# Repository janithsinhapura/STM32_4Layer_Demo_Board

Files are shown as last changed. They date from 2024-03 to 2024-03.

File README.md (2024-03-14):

Contains the project files of the design of a 4 layer STM32F103c8t6 Demo Board

+ SPI
+ I2C
+ UART
+ USB
  
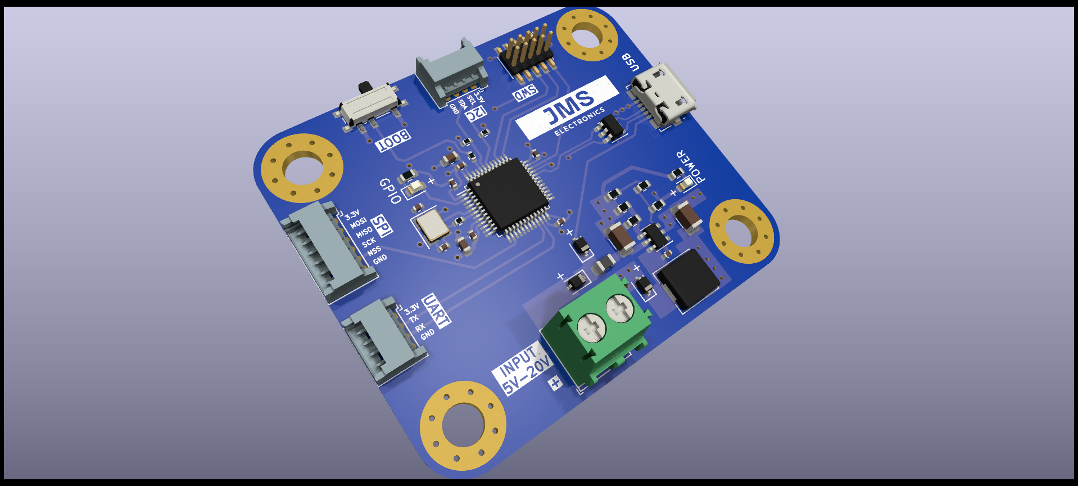
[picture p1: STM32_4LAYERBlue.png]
#D View

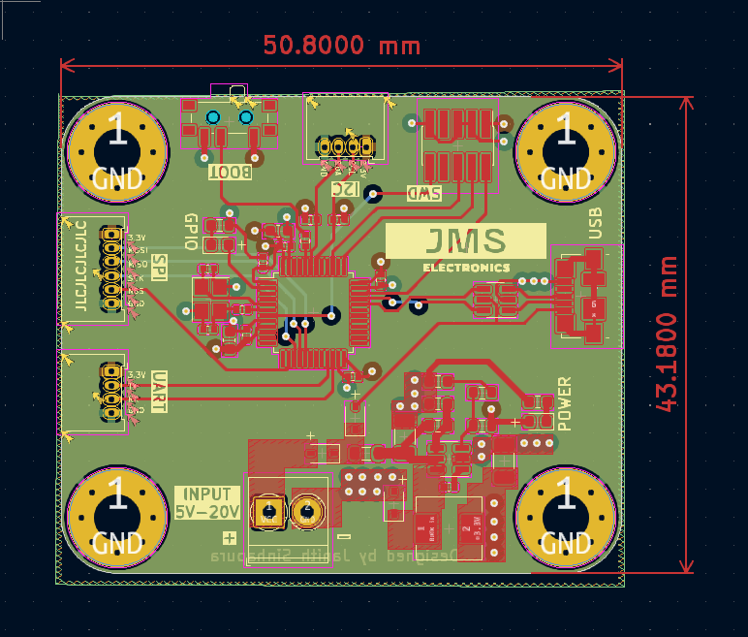
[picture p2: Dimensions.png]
Dimensions


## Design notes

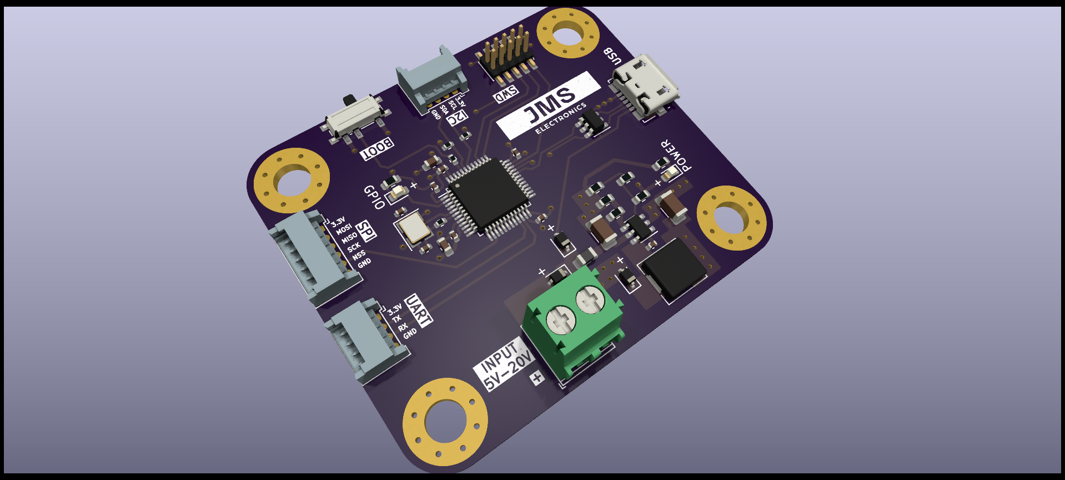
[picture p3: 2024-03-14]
STM32_4LAYER2RAY.png

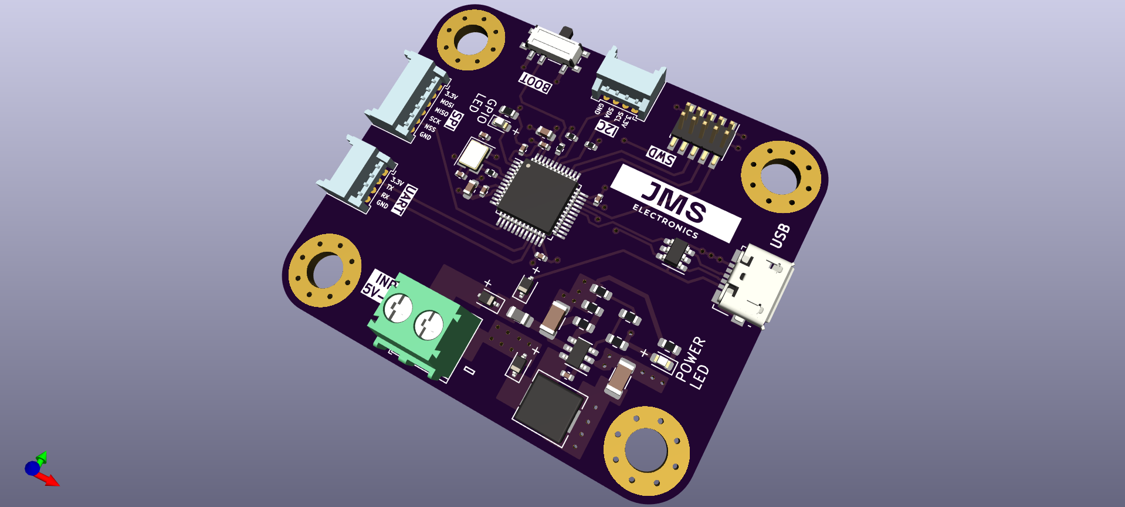
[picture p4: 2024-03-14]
STM32_4LAYER.png

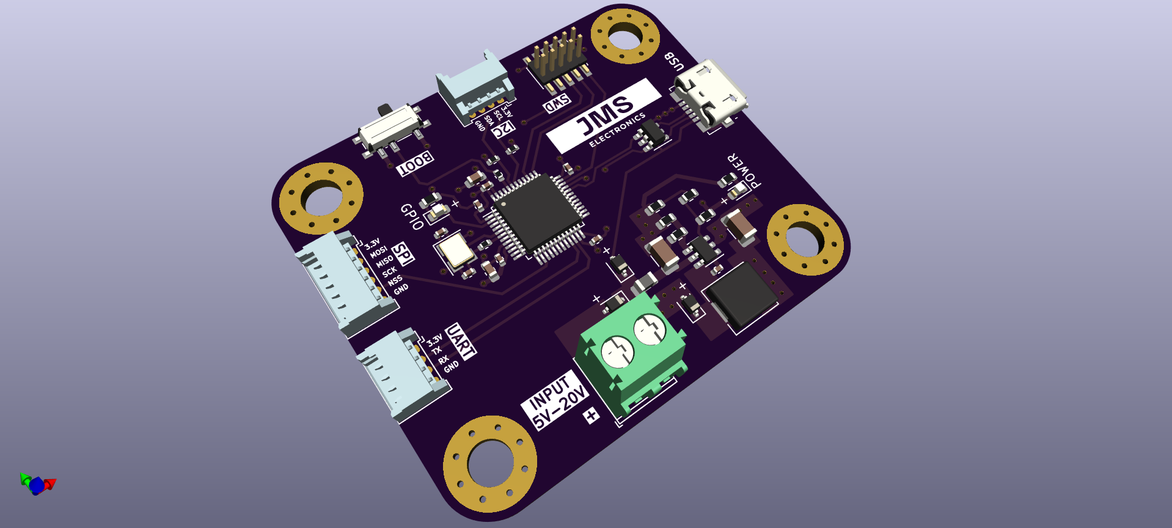
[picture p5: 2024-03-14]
STM32_4LAYER2.png

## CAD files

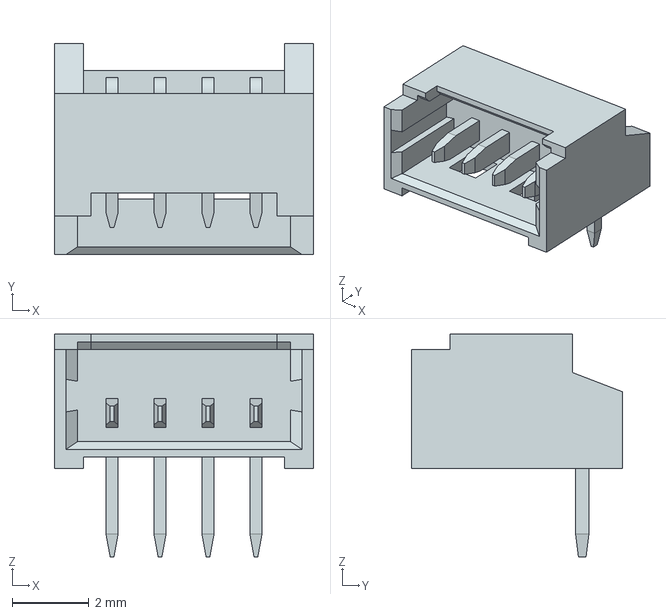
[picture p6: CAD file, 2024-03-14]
3d Models/I2C.stp
6.75 x 5.50 x 5.80 mm

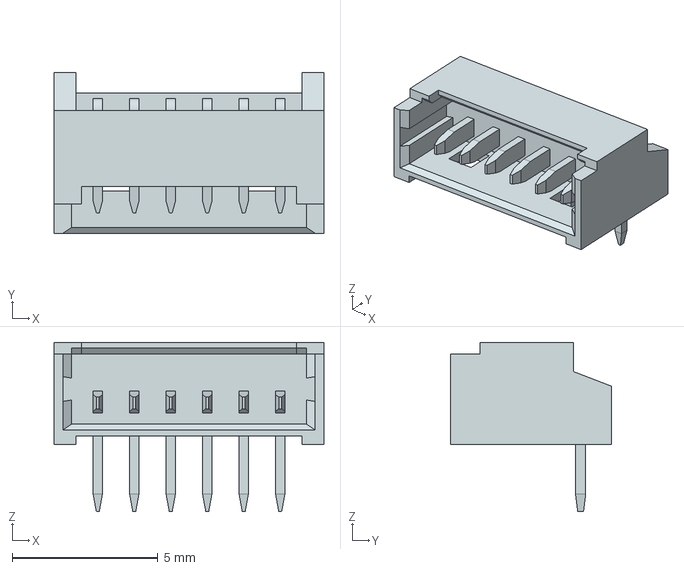
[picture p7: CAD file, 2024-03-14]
3d Models/UART.stp
9.25 x 5.50 x 5.80 mm

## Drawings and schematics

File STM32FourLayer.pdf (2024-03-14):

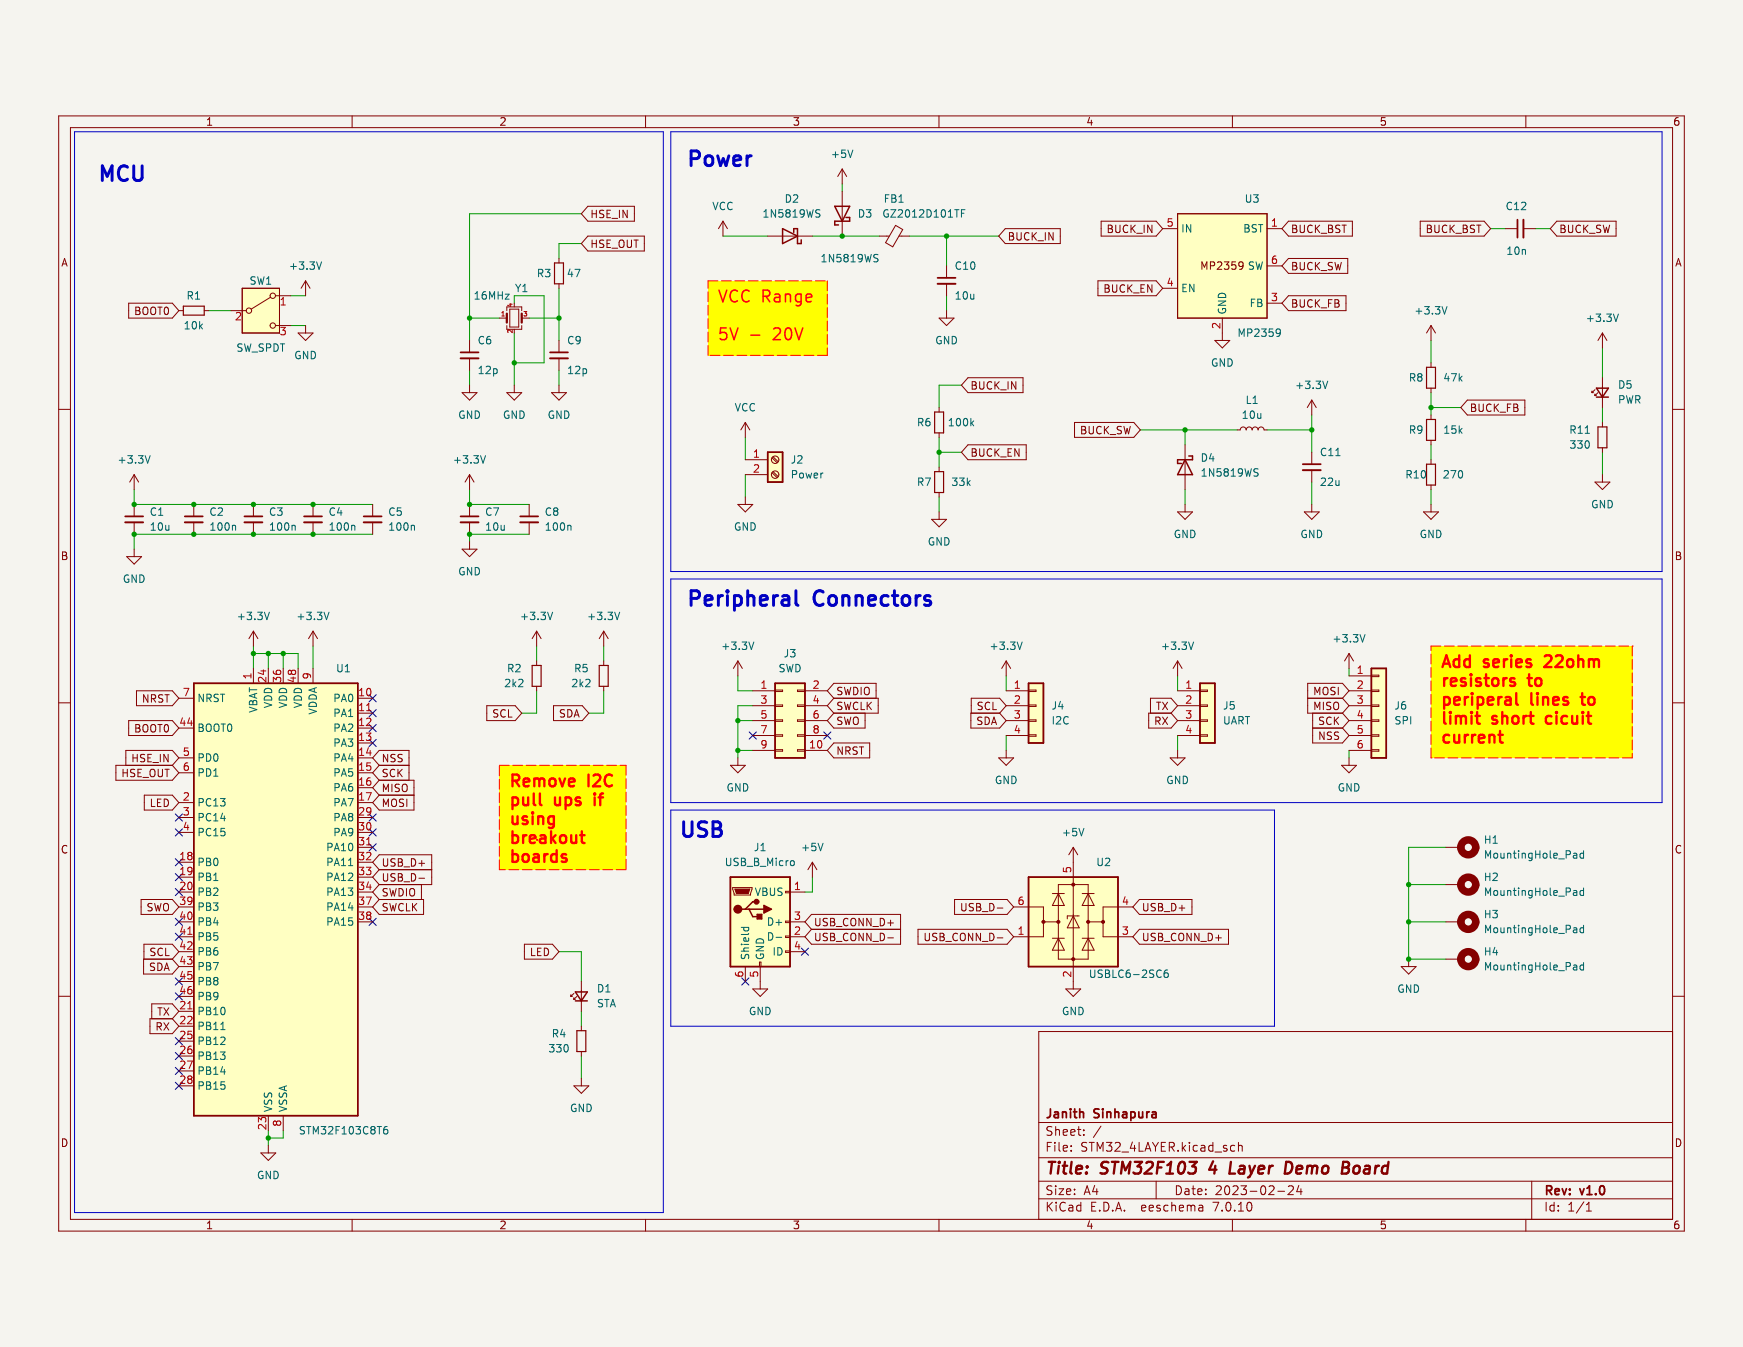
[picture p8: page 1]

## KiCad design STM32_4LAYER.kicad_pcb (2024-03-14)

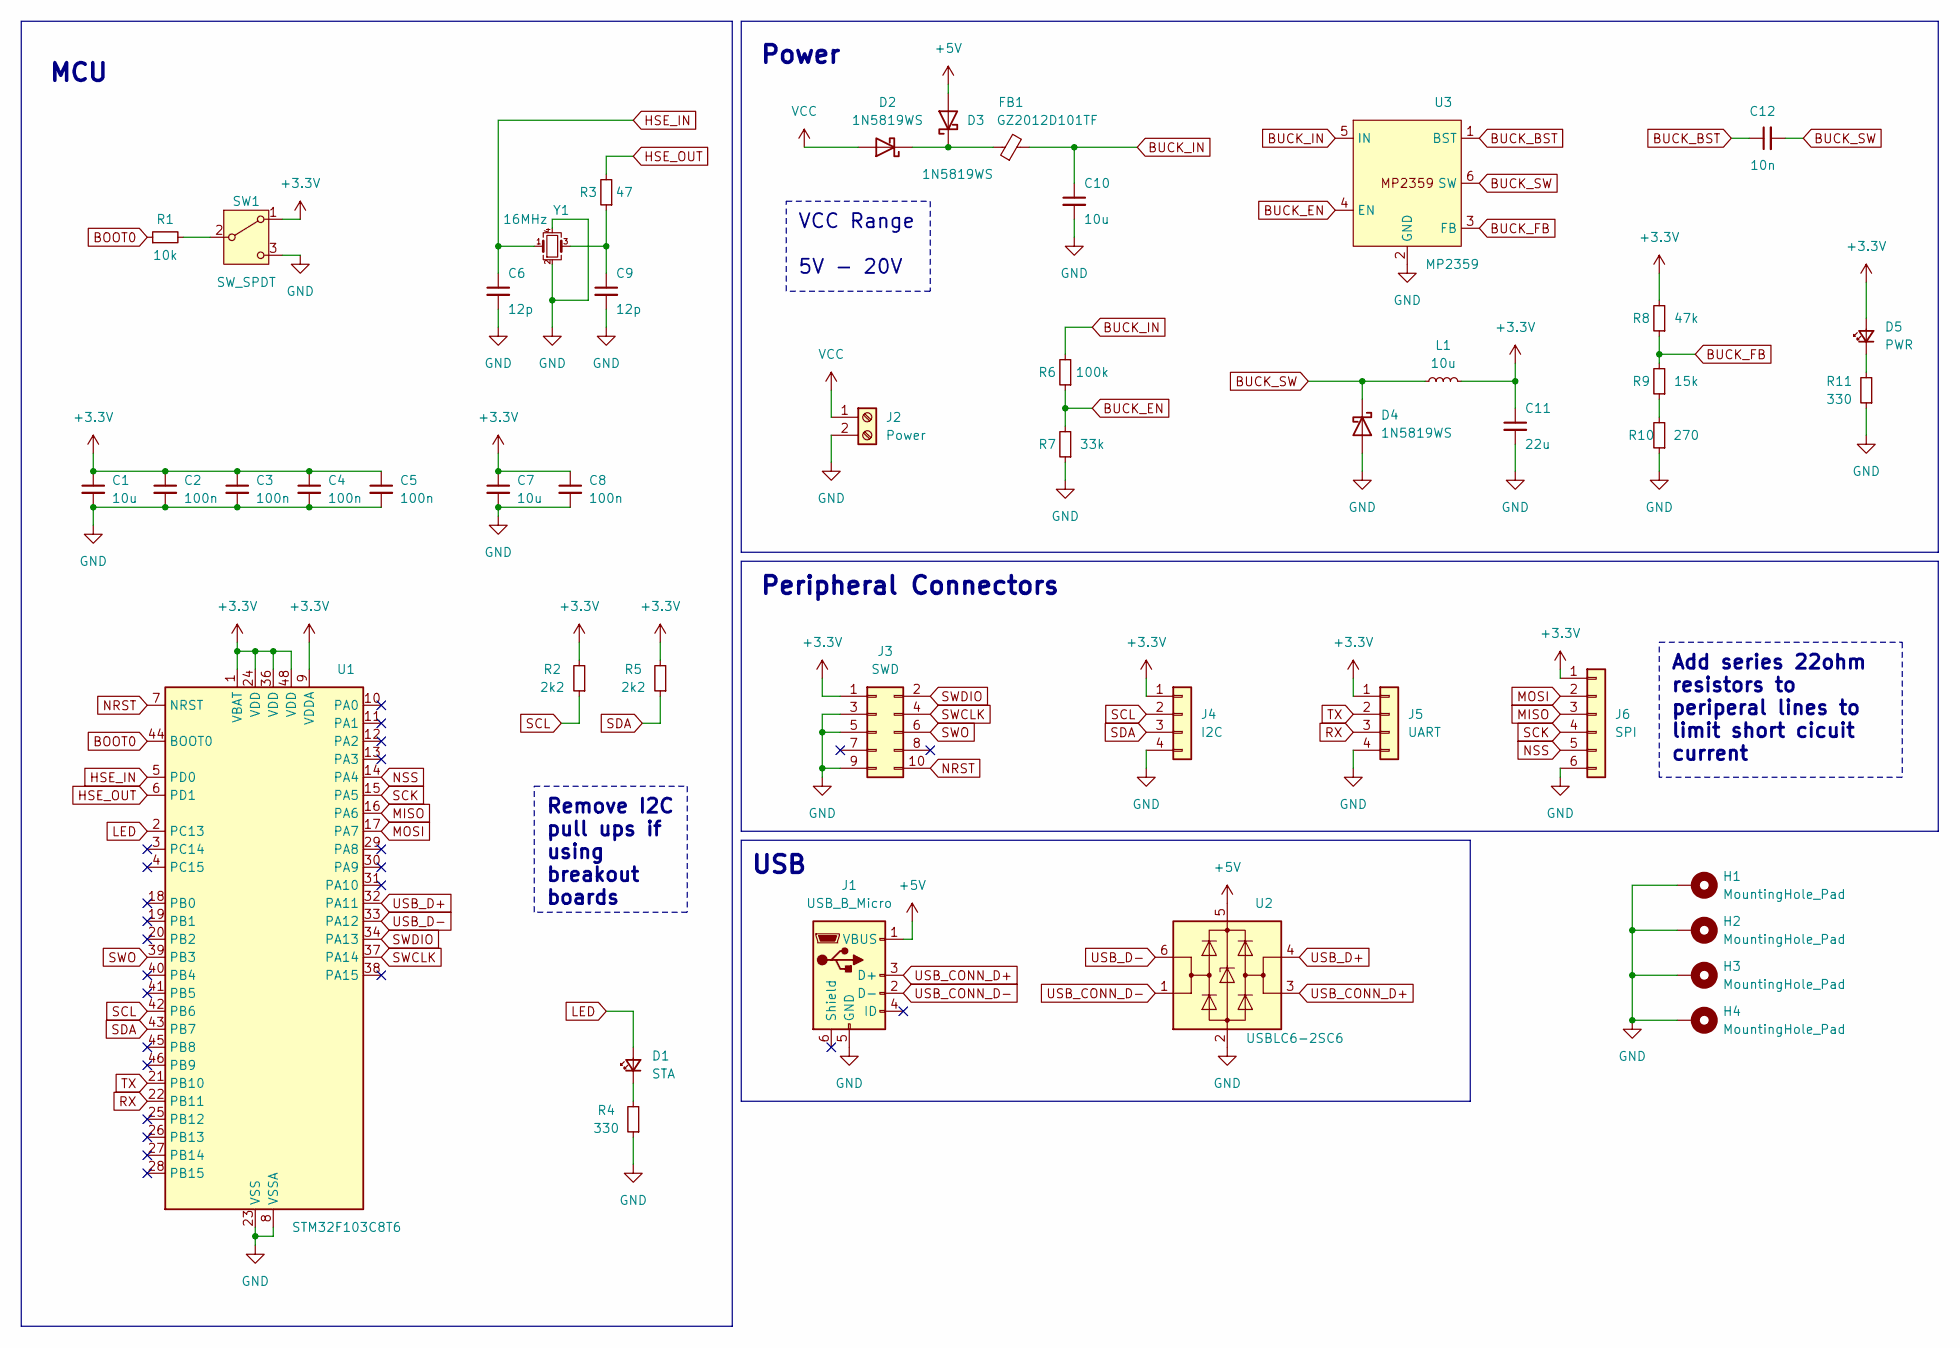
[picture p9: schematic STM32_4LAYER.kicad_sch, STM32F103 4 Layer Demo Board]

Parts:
C1, C7: 10u; C_0603_1608Metric
C2, C3, C4, C5, C8: 100n; C_0402_1005Metric
C6, C9: 12p; C_0402_1005Metric
C10: 10u; C_1206_3216Metric
C11: 22u; C_1206_3216Metric
C12: 10n; C_0402_1005Metric
D1: STA; LED_0603_1608Metric
D2, D3, D4: 1N5819WS; D_SOD-323
D5: PWR; LED_0603_1608Metric
FB1: GZ2012D101TF; L_0805_2012Metric
H1, H2, H3, H4: MountingHole_Pad; MountingHole_4.3mm_M4_Pad_Via
J1: USB_B_Micro; USB_Micro-B_Molex_47346-0001
J2: Power; TerminalBlock_Phoenix_PT-1,5-2-3.5-H_1x02_P3.50mm_Horizontal
J3: SWD; PinHeader_2x05_P1.27mm_Vertical_SMD
J4: I2C; Molex_PicoBlade_53048-0410_1x04_P1.25mm_Horizontal
J5: UART; Molex_PicoBlade_53048-0410_1x04_P1.25mm_Horizontal
J6: SPI; Molex_PicoBlade_53048-0610_1x06_P1.25mm_Horizontal
L1: 10u; L_Sunlord_MWSA0518S
R1: 10k; R_0402_1005Metric
R2, R5: 2k2; R_0402_1005Metric
R3: 47; R_0402_1005Metric
R4, R11: 330; R_0603_1608Metric
R6: 100k; R_0603_1608Metric
R7: 33k; R_0603_1608Metric
R8: 47k; R_0603_1608Metric
R9: 15k; R_0603_1608Metric
R10: 270; R_0603_1608Metric
SW1: SW_SPDT; SW_SPDT_PCM12
U1: STM32F103C8T6; LQFP-48_7x7mm_P0.5mm
U2: USBLC6-2SC6; SOT-23-6
U3: MP2359; TSOT-23-6
Y1: 16MHz; Crystal_SMD_3225-4Pin_3.2x2.5mm

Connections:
+3.3V: C1.1, C2.1, C3.1, C4.1, C5.1, C7.1, C8.1, C11.1, D5.2 (A), J3.1, J4.1, J5.1, J6.1, L1.2, R2.2, R5.2, R8.2, SW1.1 (A), U1.1 (VBAT), U1.9 (VDDA), U1.24 (VDD), U1.36 (VDD), U1.48 (VDD)
+5V: D3.2 (A), J1.1 (VBUS), U2.5 (VBUS)
BOOT0: R1.1, U1.44 (BOOT0)
BUCK_BST: C12.1, U3.1 (BST)
BUCK_EN: R6.1, R7.2, U3.4 (EN)
BUCK_FB: R8.1, R9.2, U3.3 (FB)
BUCK_IN: C10.1, FB1.2, R6.2, U3.5 (IN)
BUCK_SW: C12.2, D4.1 (K), L1.1, U3.6 (SW)
GND: C1.2, C2.2, C3.2, C4.2, C5.2, C6.2, C7.2, C8.2, C9.2, C10.2, C11.2, D4.2 (A), H1.1, H2.1, H3.1, H4.1, J1.5 (GND), J2.2, J3.3, J3.5, J3.9, J4.4, J5.4, J6.6, R4.1, R7.1, R10.1, R11.1, SW1.3 (C), U1.8 (VSSA), U1.23 (VSS), U1.35 (VSS), U1.47 (VSS), U2.2 (GND), U3.2 (GND), Y1.2, Y1.4
HSE_IN: C6.1, U1.5 (PD0), Y1.1
HSE_OUT: R3.2, U1.6 (PD1)
LED: D1.2 (A), U1.2 (PC13)
MISO: J6.3, U1.16 (PA6)
MOSI: J6.2, U1.17 (PA7)
NRST: J3.10, U1.7 (NRST)
NSS: J6.5, U1.14 (PA4)
unnamed: C9.1, R3.1, Y1.3
unnamed: D1.1 (K), R4.2
unnamed: D2.1 (K), D3.1 (K), FB1.1
unnamed: D5.1 (K), R11.2
unnamed: R9.1, R10.2
unnamed: R1.2, SW1.2 (B)
RX: J5.3, U1.22 (PB11)
SCK: J6.4, U1.15 (PA5)
SCL: J4.2, R2.1, U1.42 (PB6)
SDA: J4.3, R5.1, U1.43 (PB7)
SWCLK: J3.4, U1.37 (PA14)
SWDIO: J3.2, U1.34 (PA13)
SWO: J3.6, U1.39 (PB3)
TX: J5.2, U1.21 (PB10)
USB_CONN_D+: J1.3 (D+), U2.3 (I/O2)
USB_CONN_D-: J1.2 (D-), U2.1 (I/O1)
USB_D+: U1.32 (PA11), U2.4 (I/O2)
USB_D-: U1.33 (PA12), U2.6 (I/O1)
VCC: D2.2 (A), J2.1

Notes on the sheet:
Remove I2C pull ups if using breakout boards
VCC Range 5V - 20V
Add series 22ohm resistors to periperal lines to limit short cicuit current
Peripheral Connectors
Power
MCU
USB

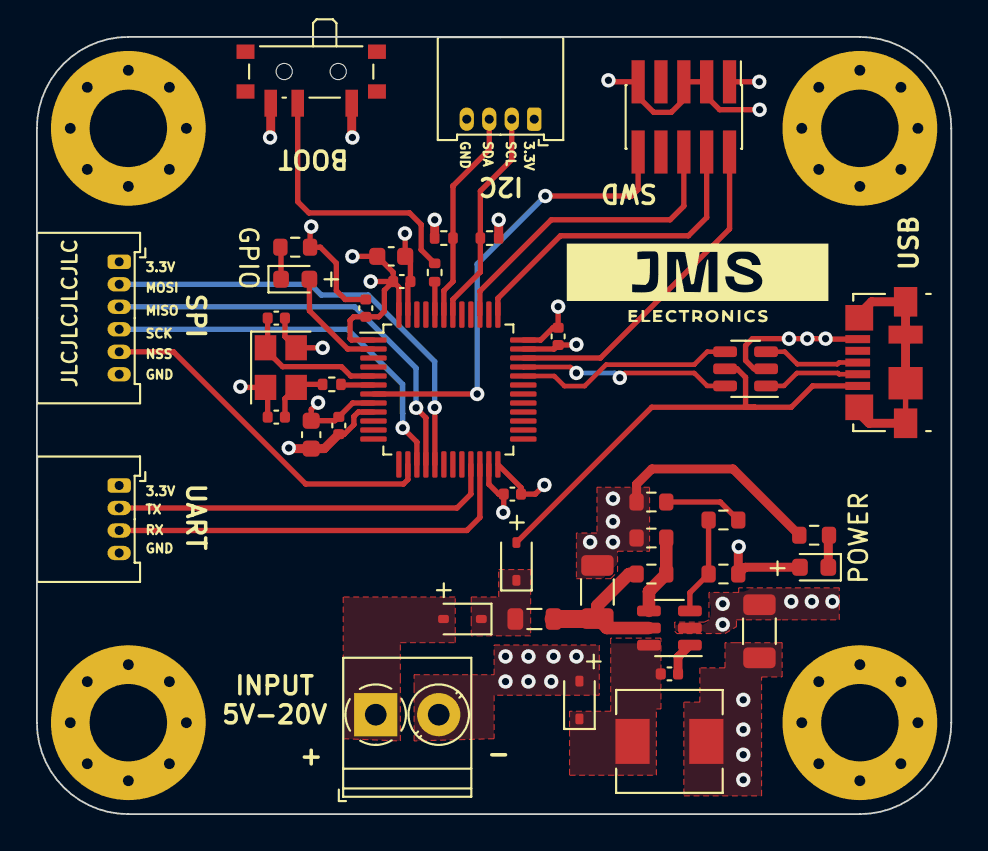
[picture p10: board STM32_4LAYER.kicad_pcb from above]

Board: 4 copper layers, 50.8 x 43.2 mm, 45 parts (0 on the bottom side), 35 nets.
